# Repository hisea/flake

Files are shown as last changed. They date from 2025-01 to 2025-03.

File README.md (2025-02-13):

<div align="center">
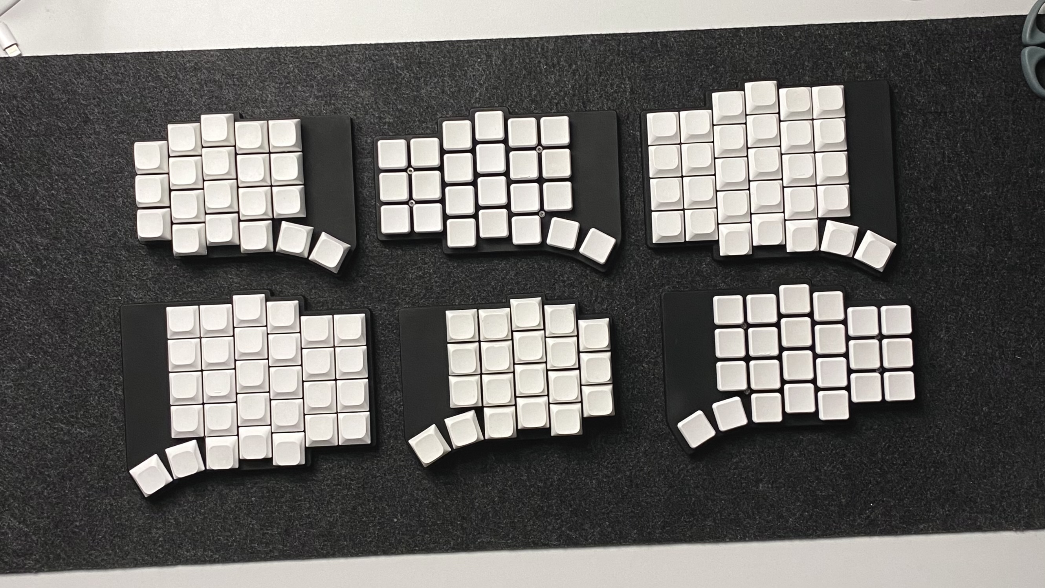
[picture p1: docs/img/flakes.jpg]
flake image
    
    <h3>Anywhy Flake</h3>
    <p><i>be productive, stay healthy and enjoy the process.</i></p>
</div>

# Why

By the 19th century, a need for a faster way of writing had emerged, which led to the invention of typewriters. Two centuries later, modern keyboards don't look much different from their predecessors, even though such design has been proven to be quite inefficient and often harmful.

Addressing these problems leads to huge benefits considering how often people use keyboards in the modern world.

# How

## Split

Regular keyboards are made in a single monolithic block, and the main problem is that such a form factor requires our forearms to meet in the center. To compensate for this, wrists are bent apart. This position creates an unnatural angle between the forearm and the wrist, which in the long term will likely lead to constant wrist pain.

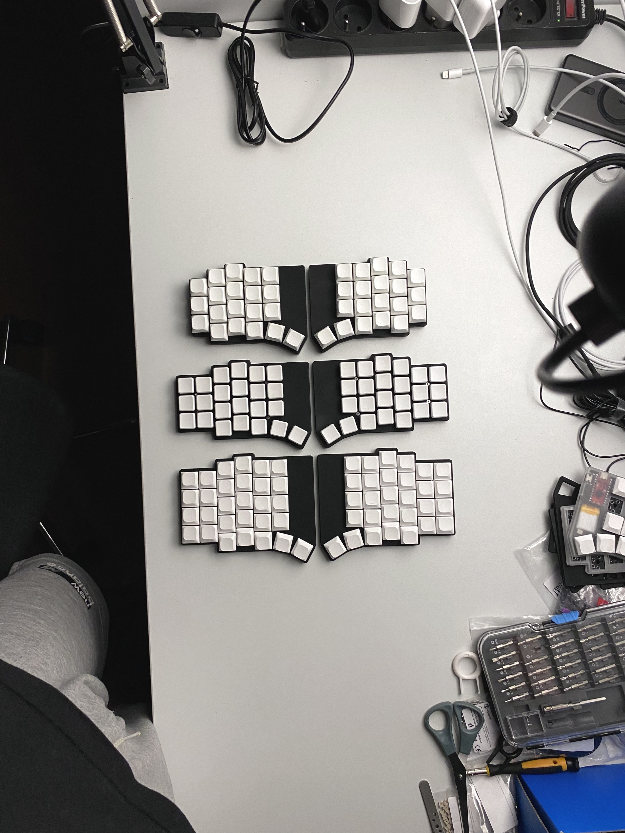
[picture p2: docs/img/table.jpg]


Each half of the split keyboard can be rotated and placed in any suitable way so everyone can adapt the setup to their personal preference, avoiding potential damage to the wrists. As a bonus, we get free space right between the halves which can be occupied by a trackpad, coffee, or even a cat =^..^=

## Stagger

If you take your hand and look at the fingers, you can notice that they are positioned horizontally. Now take a look at your keyboard - the keys are grouped in arrays that are shifted vertically, known as row-based stagger.

row-based stagger keyboard image

This well-known layout forces your fingers to move in a counterintuitive way. The solution to that problem is simple: we need to rearrange the keys in a more human-friendly way.

flake stagger image

As you can see, Flake has what's called a column-based stagger. Because of this, keys are located in the path of natural finger movement, which results in a much more pleasant typing experience and reduced fatigue.

## Key switches

There are a huge amount of various keyboard switches with different feel, size, sound, height and so on. Such variety is awesome, but the problem arrives when you have to chose one.

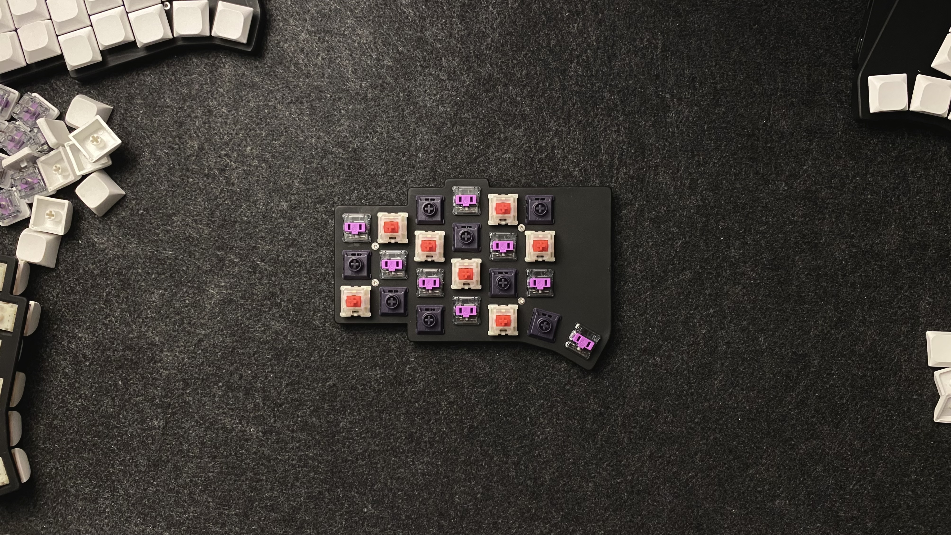
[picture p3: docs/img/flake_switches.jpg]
flake s image


To address this issue, Flake utilizes hot-swap sockets. There are two different sockets per key, allowing you to use any Cherry MX and low-profile Kailh Choc switches. This way, you can always experiment with the look and feel of the keyboard and change it according to your mood.

## Keys amount

There's a high chance that some might feel confused seeing such a small number of keys, considering user productivity is one of the priorities for Anywhy.

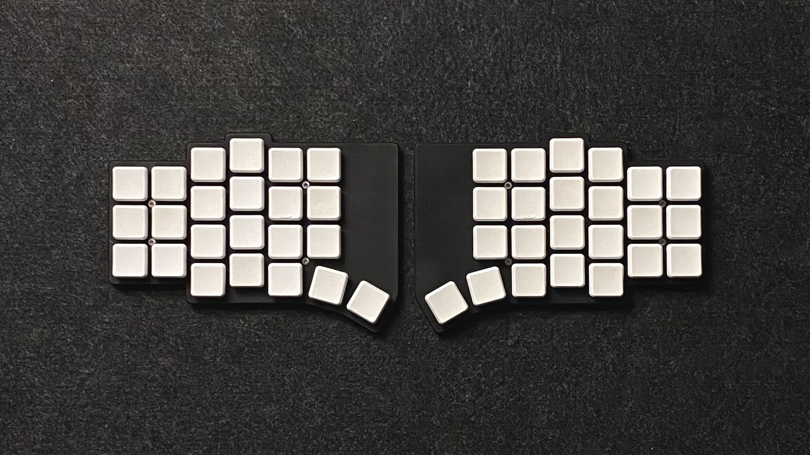
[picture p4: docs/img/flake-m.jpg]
flake s image


Indeed, Flake has fewer keys than most conventional keyboards, and that's not a compromise, but a feature. A large number of keys causes hands to move around to reach further-placed keys.

Having fewer keys doesn't mean less functionality. In fact, Flake is not only fully input-compatible with regular keyboards but also allows you to add more keys than most keyboards have. All thanks to [ZMK Firmware](https://zmk.dev) and its features such as [layers](https://zmk.dev/docs/keymaps#layers).

config showcase image

### Flake L

There's a Flake L with 58 keys for those who aren't ready to jump down the rabbit hole yet or just prefer more keys.

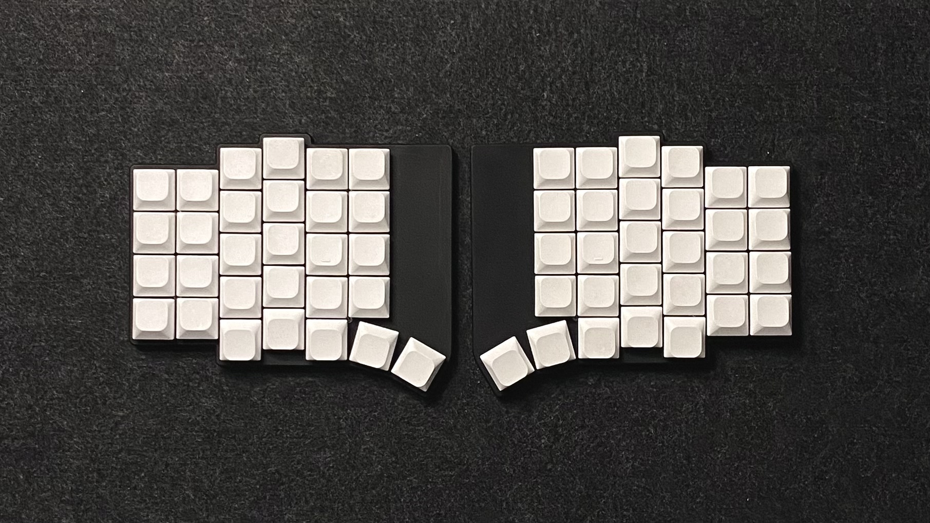
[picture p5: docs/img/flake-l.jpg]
flake l image


### Flake S

For people who strive for absolute comfort and compactness, there is also Flake S with 40 keys.

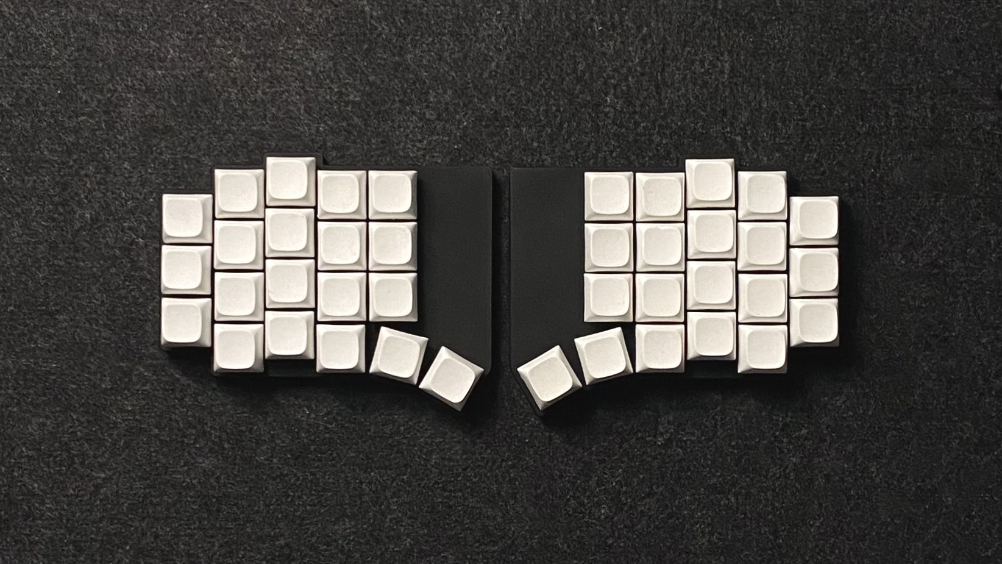
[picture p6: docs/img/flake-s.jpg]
flake s image


## Thickness

The keyboard has been designed to be as thin as possible while maintaining a sturdy construction.

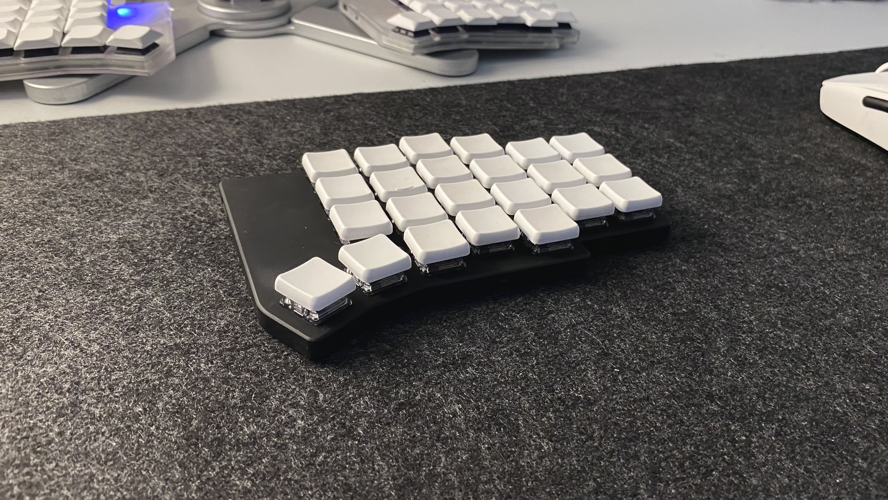
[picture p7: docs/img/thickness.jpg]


The keyboard body is only ~0.8 cm (without feet), which combined with the low-profile switches and caps, greatly enhances comfort.

# What

Flake supports both wired and wireless (Bluetooth) connection, which makes it perfect for both home usage with a PC or portable setup with a laptop, tablet, or even smartphone.

To achieve both types of connectivity, each half has two USB-C ports, one on the top and one on the inner side. The side port is used to connect the halves together, and then one of them (usually the left one) can be connected to any device using the top port, which is also used to charge the keyboard.

> Ports on the side are used only to communicate with each other, so they can't be used to charge the keyboard or to flash the new firmware

The keyboard allows for a maximum battery capacity of 200mah. On a single charge, the left half will last ~1 month and the right half will last over 4 months when used for 6 hours every day.

> The calculations are done with the nice!nano controller.

In order to use MX Switches, the special "plate" comes with the Flake which should be placed between the board and the switches.

# Build

If you want to build the keyboard yourself, check out [Guide](./docs/build_guide.md), which describes everything you need to build your own Flake. 

Also, make sure to check out the [Gallery ✨](./docs/gallery.md) with awesome Flake builds.

# Credits

Huge thanks to:

- [@foostan](https://github.com/foostan), the author of [Corne Keyboard](https://github.com/foostan/crkbd) which was my introduction to the world of ergonomic keyboards.
  
- [@pashutk](https://github.com/pashutk), the author of [Chocofi](https://github.com/pashutk/chocofi), an amazing tiny keyboard I've been using for a while.
  
- [@ebastler](https://github.com/ebastler/) for his amazing [marbastlib](https://github.com/ebastler/marbastlib) which is being used as the basis for footprint switches

- [@josefadamcik](https://github.com/josefadamcik), the author of [Sofle](https://github.com/josefadamcik/SofleKeyboard) which gave huge inspiration for the Flake's key layout.
  
- [@petejohanson](https://github.com/petejohanson) for creating [ZMK Firmware](https://github.com/zmkfirmware/zmk) and all the [contributors](https://github.com/zmkfirmware/zmk/graphs/contributors) that make it better each day.

- Everyone working on [KiCad](https://gitlab.com/kicad/code/kicad) and [FreeCAD](https://github.com/FreeCAD/FreeCAD), for creating such powerful open source tools

- People from the [ZMK discord server](https://zmk.dev/community/discord/invite) for being so kind while helping me learn how to design PCB and how to debug and solve various problems.

- Finally, thank you to everyone who explores unpopular technologies, digs into niche topics, and makes amazing things possible.

## Stars

Your stars give motivation to keep improving the project :)

Star History Chart (https://star-history.com/#anywhy-io/flake&Date)

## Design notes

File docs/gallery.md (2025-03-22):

# Anywhy Flake Gallery

Welcome to the gallery, here you will find amazing Flake builds made by people. This page will be constantly expanding, so if you have a build you want to share, feel free to contact me and I'll add it here.

## by [@peppapighs](https://www.reddit.com/r/ErgoMechKeyboards/comments/1jbw0kt/my_custom_flake/)

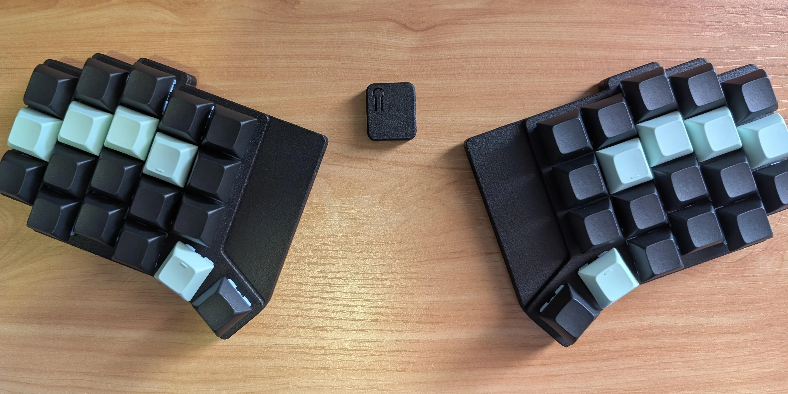
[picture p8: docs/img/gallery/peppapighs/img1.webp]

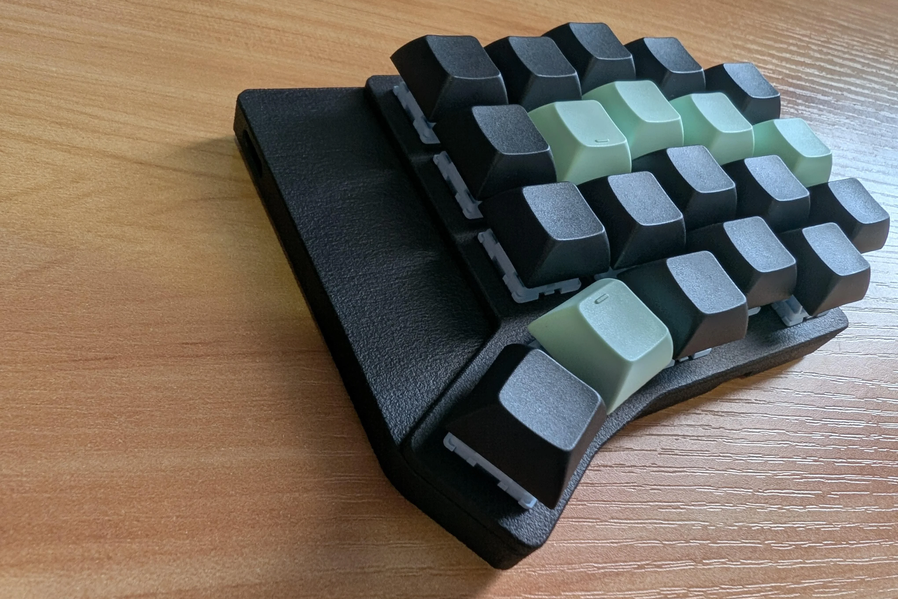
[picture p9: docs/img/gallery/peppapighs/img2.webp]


Flake S with modified PCB adding through-holes for MCU mounting

## by [@caiodelgado](https://www.reddit.com/r/ErgoMechKeyboards/comments/1iz07kw/anywhy_flake_choc_v1_robinsunset_tenting/)

Flake with Choc v1 Robin switches, 3d-printed keycaps and tenting legs

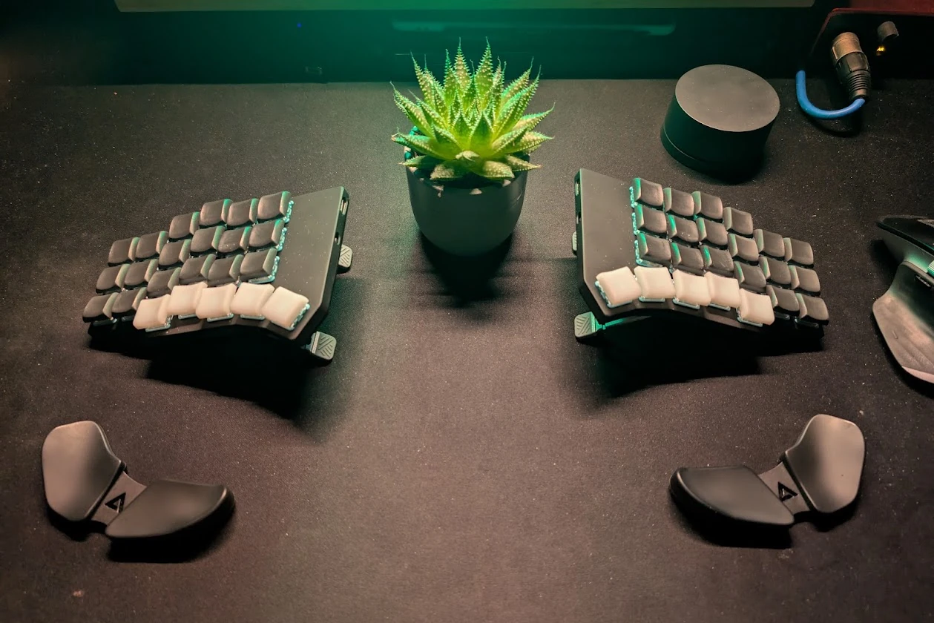
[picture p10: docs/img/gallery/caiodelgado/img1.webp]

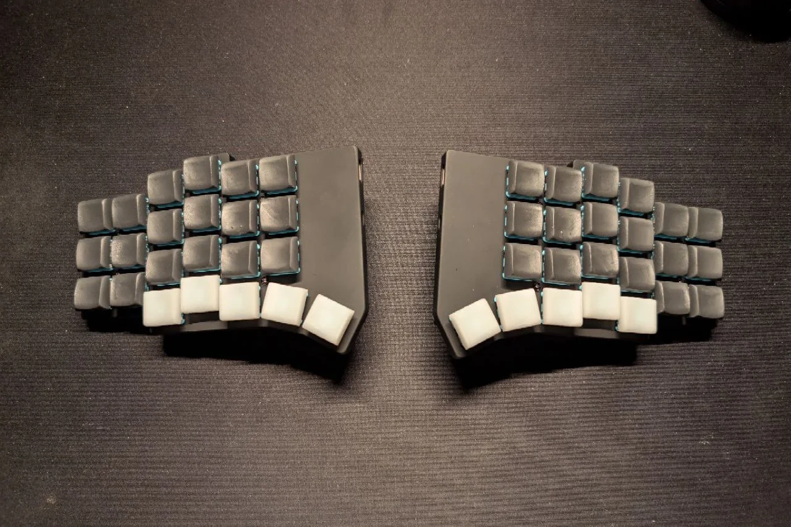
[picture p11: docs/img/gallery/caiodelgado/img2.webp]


## by [@kurisutofujp](https://www.reddit.com/r/ErgoMechKeyboards/comments/1iirgyt/comment/mb9034h/)

Snow-white Flake L with MX switches

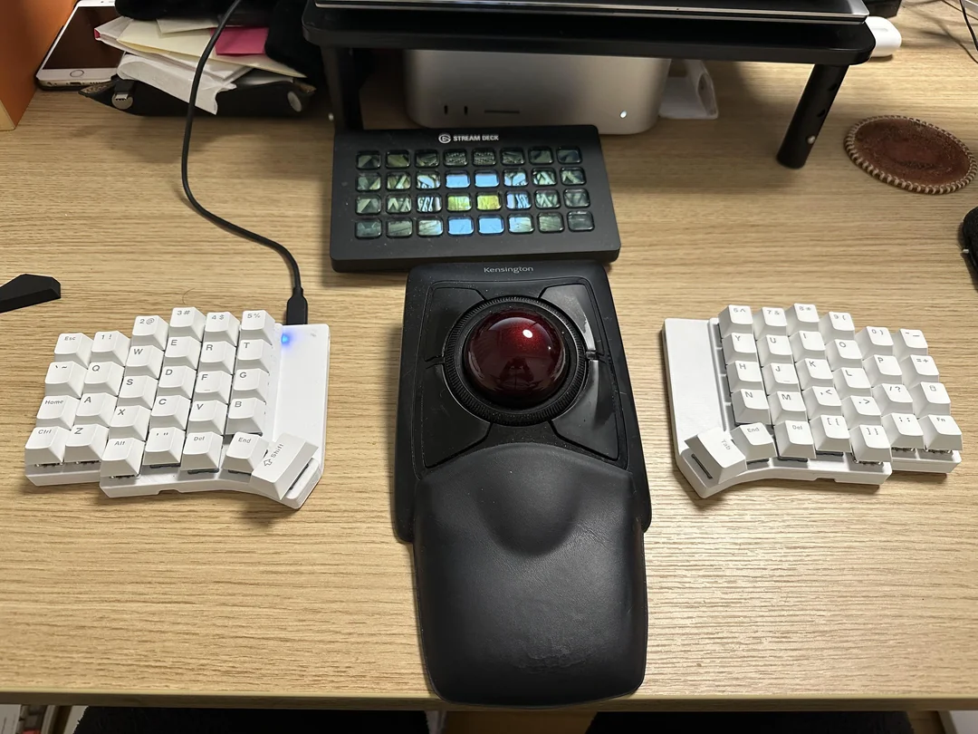
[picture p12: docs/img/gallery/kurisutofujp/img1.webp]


## by [@devpew](https://www.reddit.com/r/ErgoMechKeyboards/comments/1ieevvh/flake/)

Clean white Flake M with black keyscaps

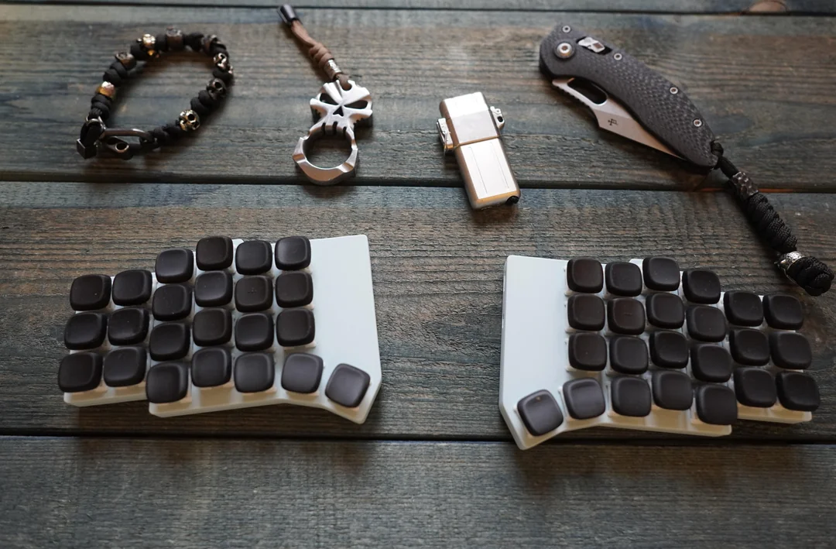
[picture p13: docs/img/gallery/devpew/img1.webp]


## by [@CaptLynx](https://www.reddit.com/r/ErgoMechKeyboards/comments/1ic3nkc/caitlynarcane_themed_anywhy_flake/)

The design is inspired by Caitlin, a character from the Arcane series.

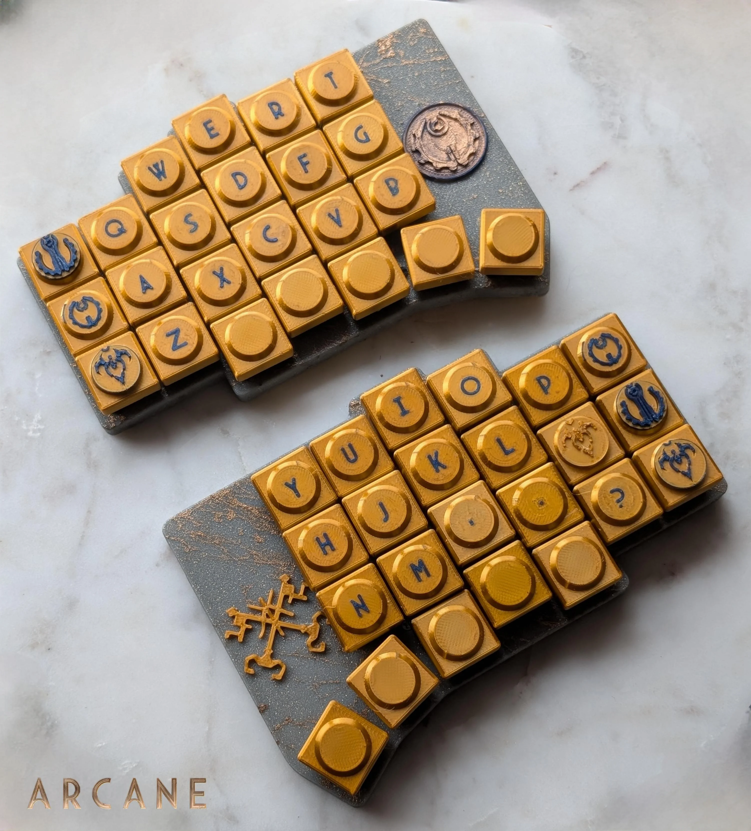
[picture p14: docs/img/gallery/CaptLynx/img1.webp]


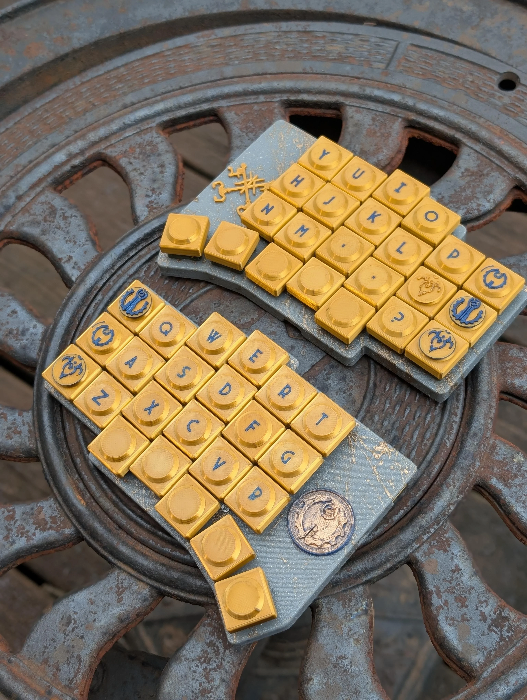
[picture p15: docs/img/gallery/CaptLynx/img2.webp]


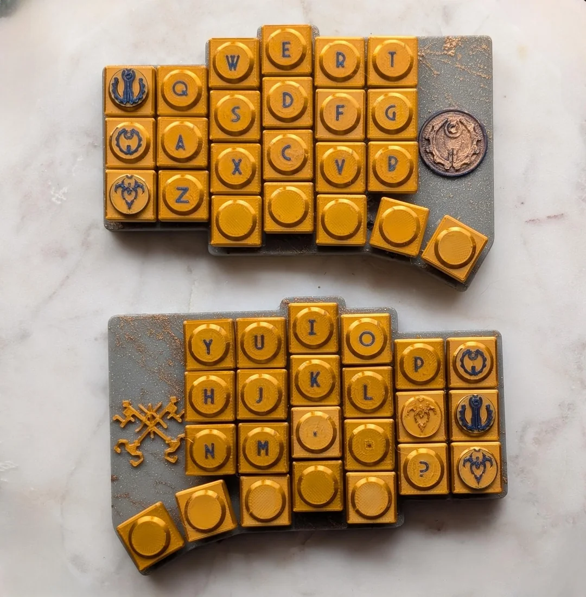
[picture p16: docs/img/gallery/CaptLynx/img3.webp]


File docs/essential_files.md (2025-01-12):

# Where is the PCB Gerber file?

You can find these files in their respective directories based on keyboard size:

```
pcb/<keyboard-size>/production/
```

Download the appropriate Gerber files for your keyboard version:

- [Flake S/M](https://github.com/anywhy-io/flake/blob/main/pcb/M%2CS/production/Flake.zip)
- [Flake L](https://github.com/anywhy-io/flake/blob/main/pcb/L/production/Flake-L.zip)
  
# Where are the Enclosure files?

Enclosure files are organized by keyboard size in the following directory structure:

```
enclosure/<keyboard-size>/
```

Select the enclosure files matching your keyboard version:

- [Flake S](https://github.com/anywhy-io/flake/tree/main/enclosure/S)
- [Flake M](https://github.com/anywhy-io/flake/tree/main/enclosure/M)
- [Flake L](https://github.com/anywhy-io/flake/tree/main/enclosure/L)

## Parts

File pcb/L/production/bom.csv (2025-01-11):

Designator | Footprint | Quantity | Value | LCSC Part #
BT1, BT2 | JST_1.25mm_mid-mount | 2 | Battery
D1, D10, D11, D12, D13, D14, D15, D16, D17, D18, D19, D2, D20, D21, D22, D23, D24, D25, D26, D27, D28, D29, D3, D30, D31, D32, D33, D34, D35, D36, D37, D38, D39, D4, D40, D41, D42, D43, D44, D45, D46, D47, D48, D49, D5, D50, D51, D52, D53, D54, D55, D56, D57, D58, D6, D7, D8, D9 | D_SOD-323_HandSoldering | 58 | D
J1, J2 | USB-C_6Pin_Mid-mount | 2 | USB_C_Receptacle_PowerOnly_6P
RSW1, RSW2 | TS-1289VE-4 | 2 | Reset_SW
SW1, SW10, SW11, SW12, SW13, SW14, SW15, SW16, SW17, SW18, SW19, SW2, SW20, SW21, SW22, SW23, SW24, SW25, SW26, SW27, SW28, SW29, SW3, SW30, SW31, SW32, SW33, SW34, SW35, SW36, SW37, SW38, SW39, SW4, SW40, SW41, SW42, SW43, SW44, SW45, SW46, SW47, SW48, SW49, SW5, SW50, SW51, SW52, SW53, SW54, SW55, SW56, SW57, SW58, SW6, SW7, SW8, SW9 | SW_MX_Choc-v1v2_Hotswap | 58 | SW_Push
U1, U2 | ProMicro_SMD | 2 | ProMicro

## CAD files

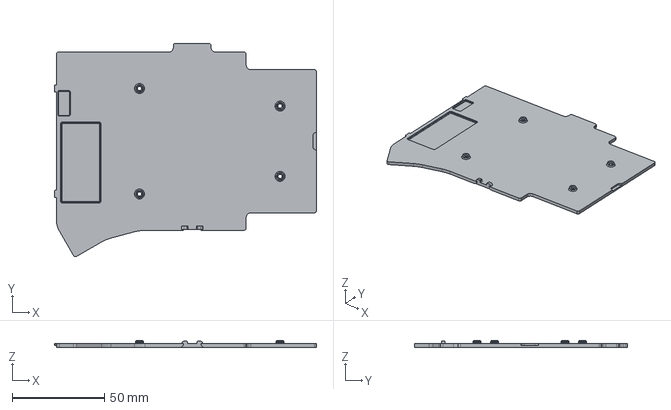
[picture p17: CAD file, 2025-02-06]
enclosure/L/Enclosure-L-Bottom-Right.step
141.6 x 115.4 x 3.70 mm

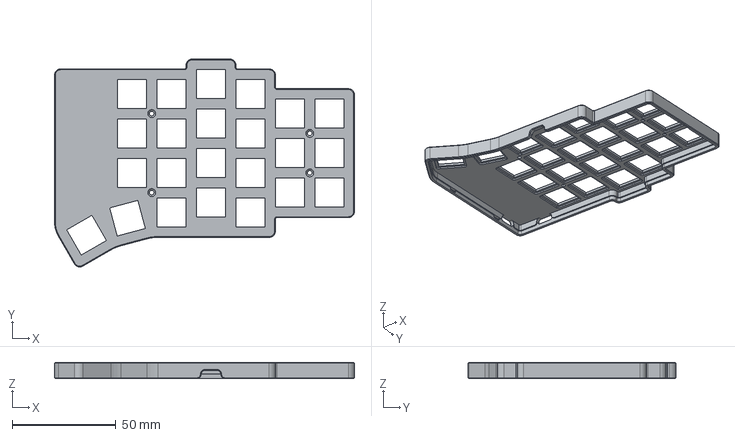
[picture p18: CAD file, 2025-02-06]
enclosure/M/Enclosure-M-Top-Right.step
144.2 x 100.0 x 7.80 mm

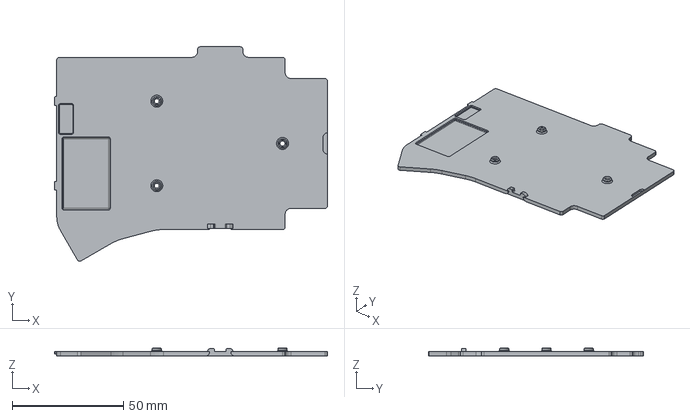
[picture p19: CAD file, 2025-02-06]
enclosure/S/Enclosure-S-Bottom-Right.step
122.6 x 96.4 x 3.70 mm

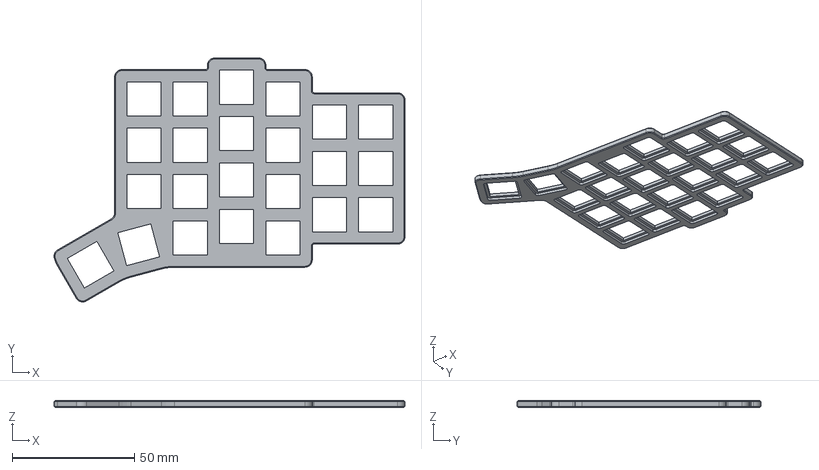
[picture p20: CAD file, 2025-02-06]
enclosure/M/Enclosure-M-Plate-Right.step
143.8 x 100.0 x 2.80 mm

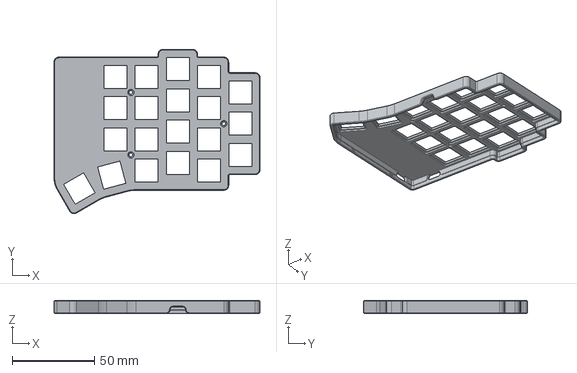
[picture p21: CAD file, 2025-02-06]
enclosure/S/Enclosure-S-Top-Right.step
125.2 x 100.0 x 7.80 mm

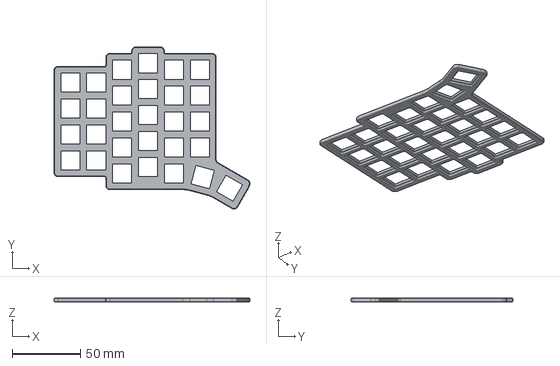
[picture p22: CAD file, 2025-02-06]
enclosure/L/Enclosure-L-Plate-Left.step
143.8 x 119.0 x 2.80 mm

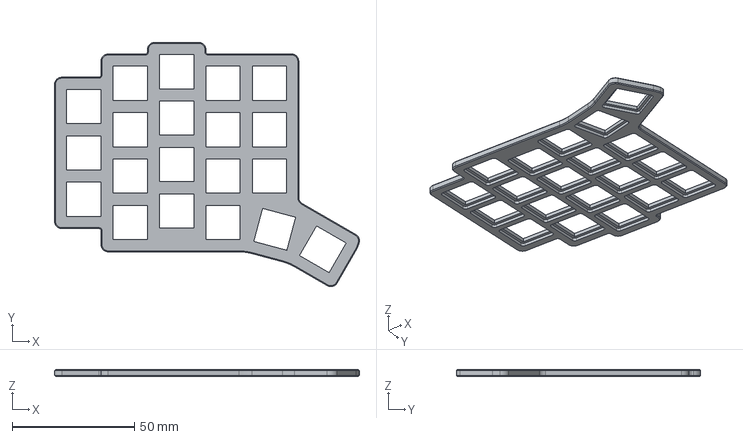
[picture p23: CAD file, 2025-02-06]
enclosure/S/Enclosure-S-Plate-Left.step
124.8 x 100.0 x 2.80 mm

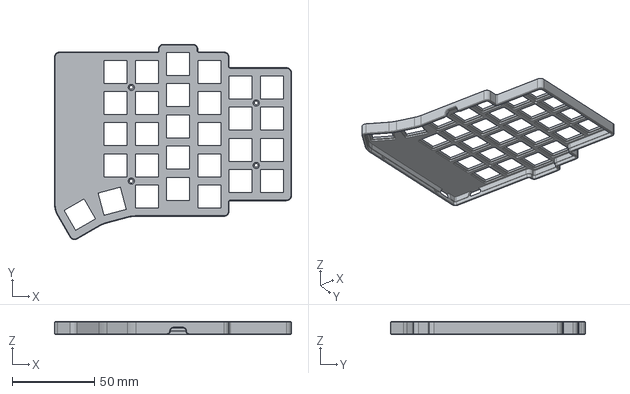
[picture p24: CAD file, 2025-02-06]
enclosure/L/Enclosure-L-Top-Right.step
144.2 x 119.0 x 7.80 mm

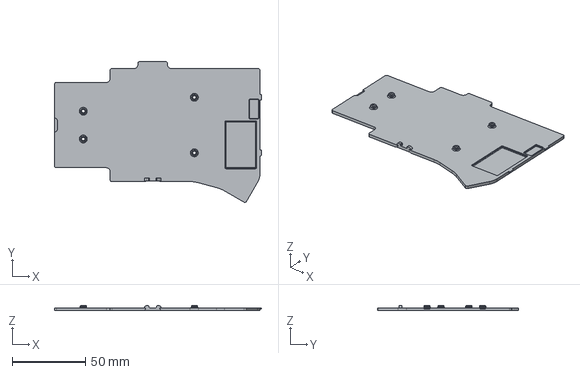
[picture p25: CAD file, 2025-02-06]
enclosure/M/Enclosure-M-Bottom-Left.step
141.7 x 96.4 x 3.70 mm

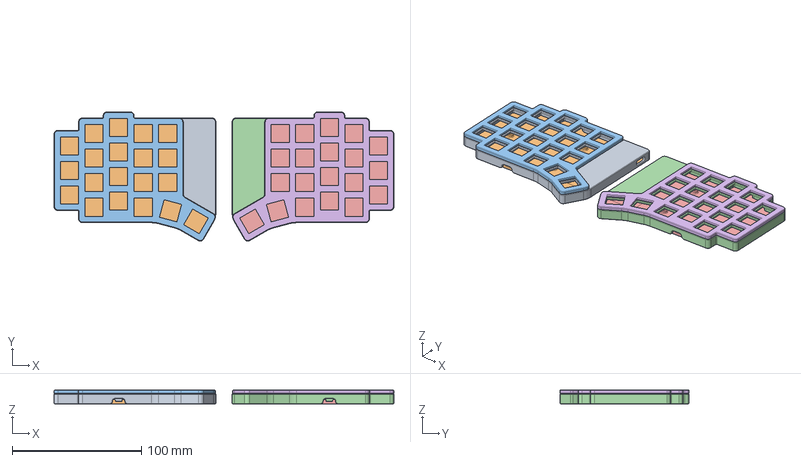
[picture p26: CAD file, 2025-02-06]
enclosure/S/Enclosure-S.FCStd
263.0 x 100.0 x 10.8 mm
Top-Left
Bottom-Left
Plate-Left
Top-RIght
Bottom-Right
Plate-Right

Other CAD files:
enclosure/L/Enclosure-L-Bottom-Left.step
enclosure/M/Enclosure-M-Top-Left.step
enclosure/S/Enclosure-S-Bottom-Left.step
enclosure/L/Enclosure-L-Plate-Right.step
enclosure/M/Enclosure-M-Bottom-Right.step
enclosure/L/Enclosure-L-Top-Left.step
enclosure/M/Enclosure-M-Plate-Left.step
enclosure/S/Enclosure-S-Plate-Right.step
enclosure/L/Enclosure-L.FCStd
enclosure/M/Enclosure-M.FCStd
enclosure/S/Enclosure-S-Top-Left.step

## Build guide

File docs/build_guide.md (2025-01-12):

# How to Build the Flake?

## Components

To build the Flake, you'll need the following materials:

| Name | Count | Remarks |
|:---|:---|:---|
| PCB | 1 set | |
| MX hot-swap sockets | 40/46/58  | |
| Choc hot-swap sockets | 40/46/58  | |
| Diodes | 40/46/58  | 1N4148 SOD-323 |
| Switches | 40/46/58  | Choc V1/V2 or MX switches |
| Keycaps | 40/46/58  | Compatible with your switches |
| Controllers | 2 | Any ProMicro-compatible controller |
| USB-C ports | 2 | 6 pins, mid-mount 1.6mm ([example](https://www.lcsc.com/product-detail/USB-Connectors_BXCONN-UC19-0B06F65011_C36936556.html))|
| Reset buttons | 2 | TS-1289VE-4 |
| Enclosure | 1 set | |
| Plates | 1 set | Required for MX switches |
| M2 Screws | 8 | Flat countersunk 8mm (e.g., DIN965)  |
| M2 Hex nuts | 8 | DIN439 (thinner than regular) |
| Rubber feet | 8 | 6x2mm |
| Battery sockets | 2 | JST 1.25 with straight pins |
| Batteries | 2 | 402030 (or smaller) with JST 1.25 |

[Here](essential_files.md) you can read where to find all the files you need for the PCBs and enclosures manufacture.

> **Note**: MX switch plates and batteries are optional depending on your build:
> - Skip the plates if are going to use only Choc switches
> - Omit batteries if plan to use Flake only by wire

# Assembly

> ⚠️ **Important**: The soldering process can be challenging, especially for beginners. This guide is structured to tackle the most difficult parts first to minimize component waste if something goes wrong. I recommend reading the guide completely before starting assembly. For first-time builders, having spare PCBs and parts is advised.

## Preparing the PCB

The PCB consists of two halves connected by breakaway tabs.

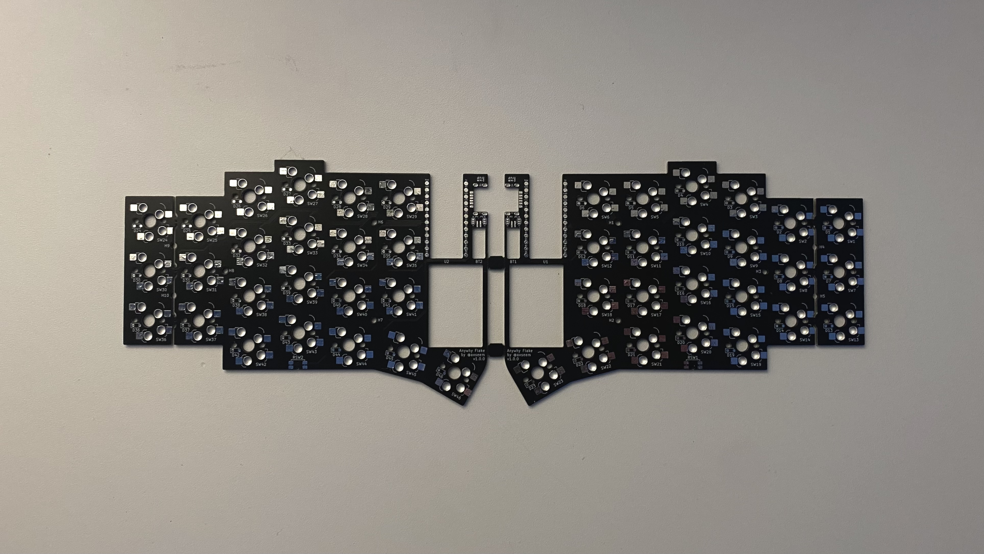
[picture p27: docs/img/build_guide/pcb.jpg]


Carefully separate the halves using pliers. Handle the top section with extra care - it remains fragile until the controller is installed.

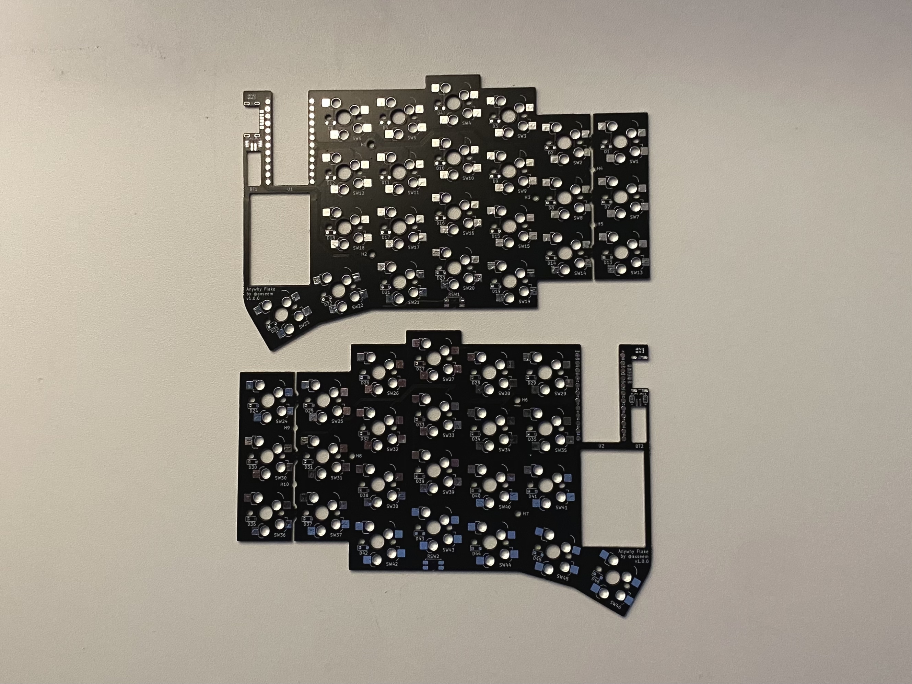
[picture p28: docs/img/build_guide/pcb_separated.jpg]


Since the assembly process is identical for both halves, this guide will focus on building one half. Simply repeat these steps for the second half.

Select the PCB half you'll assemble first.

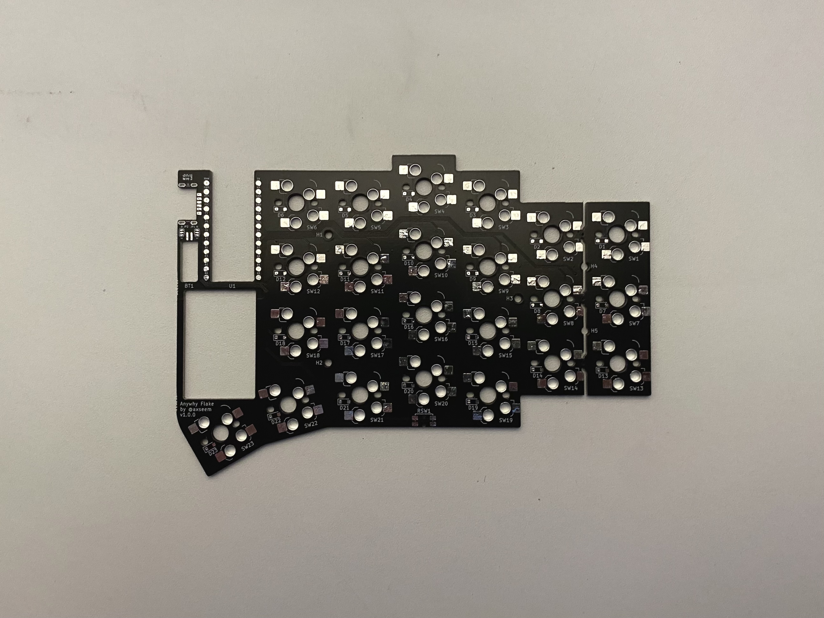
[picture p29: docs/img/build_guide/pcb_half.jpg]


If you're building the S version with 40 keys, now is the time to remove the outer column. To do this, hold the PCB with the bottom side facing you (as shown in the previous image) and gently fold it toward you until it breaks.

For M or L versions, keep the PCB as is.

## USB Port

> **Note**: The outer pins and legs are connected to the GND (Ground) net, which contains substantial copper and requires more heat to solder properly. To ensure good connection, use additional flux and slightly increase the iron temperature, but avoid keeping the iron on the pad for too long.

Place the USB-C port in the appropriate cutout marked as J1 or J2, depending on which half you're working on. Ensure the port's back sits flush against the PCB.

Apply a small amount of flux over the pins. Touch each of the six pads briefly with your soldering iron tip and solder wick. Use just enough solder to secure the port without creating bridges between pins.

If bridges occur, apply flux and remove excess solder with your iron.

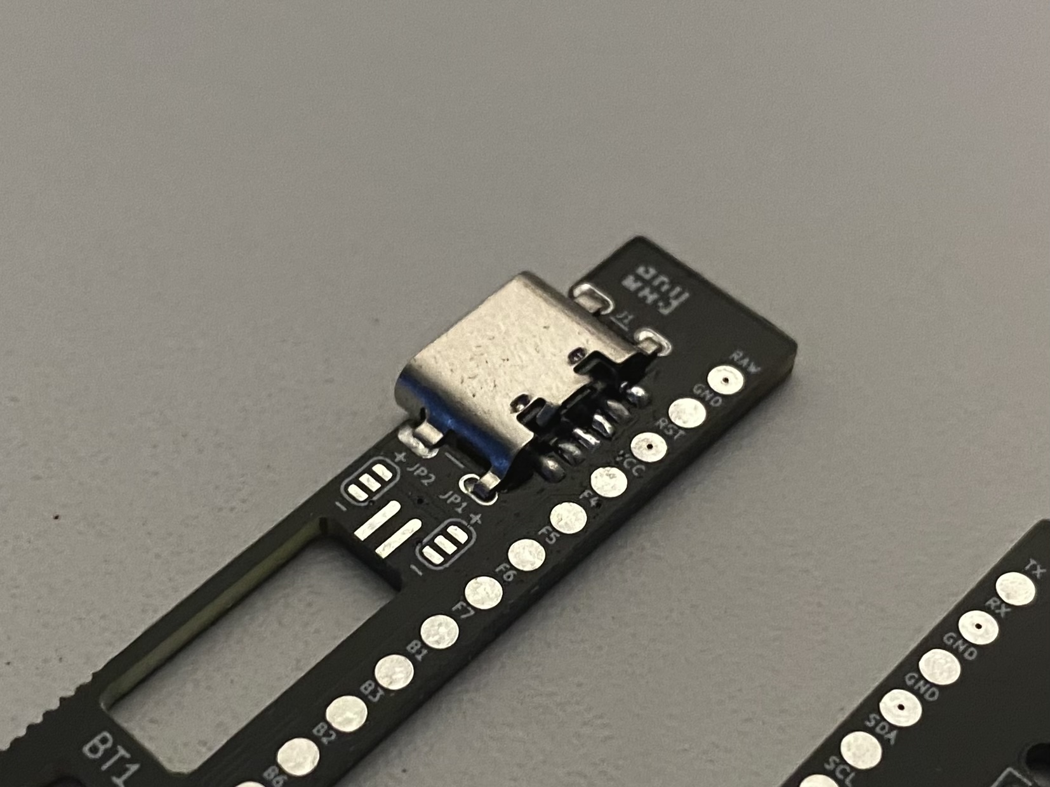
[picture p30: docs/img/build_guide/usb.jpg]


After soldering the pins, flip the PCB and solder the legs. Hold the iron over each hole for a few seconds to allow the solder to flow into it. Use a moderate amount of solder so it will not stick out of the PCB surface.

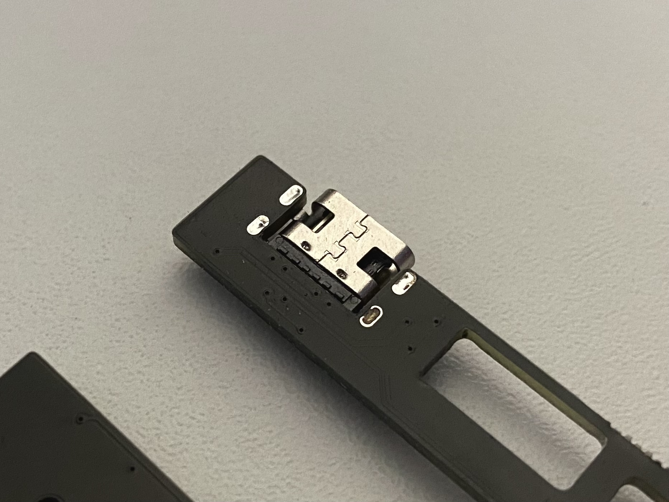
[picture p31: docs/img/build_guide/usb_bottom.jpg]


> **Tip**: A good practice is to test the connections with a multimeter after soldering. The pins are symmetrically connected to the nets:
>
> | Pins | Net | Description |
> |------|-----|-------------|
> | 1, 6 | GND | Ground      |
> | 2, 5 | VCC | Power       |
> | 3, 4 | RX  | Data        |
>
> Locate these network names on the controller pads and verify proper connections.

## Battery Connector

Add solder to one of the long connector pads and apply flux. Insert the JST 1.25 socket into the BT1 hole (or BT2 for the other half) with the cutout facing downward. Hold the connector with tweezers, ensuring the legs lay flat on the pads. Apply soldered iron tip to the leg above the pre-soldered pad. Once one leg is secured, solder the second leg.

Verify the connector sits parallel to the PCB. If needed, reheat the legs to adjust position. Check for any bridges between legs.

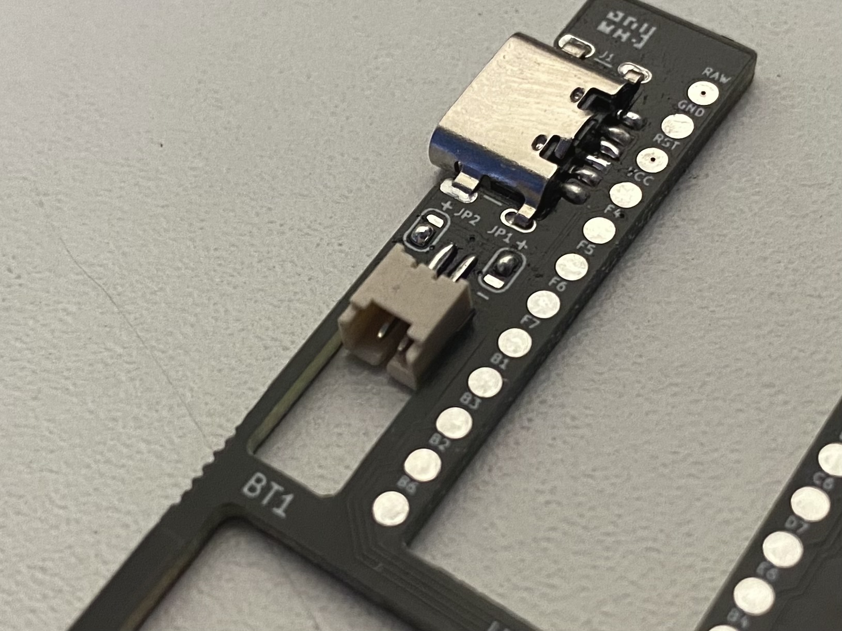
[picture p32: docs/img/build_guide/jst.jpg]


Next, solder jumpers JP1 and JP2 (or JP3 and JP4, depending on the half). First, insert the battery into the socket and note the wire polarity from left to right. Remove the battery and solder the jumpers accordingly. For example, if you noted black (negative) then red (positive), solder the center and bottom pad on the left jumper and the center and top pad on the right jumper.

> ⚠️ **Warning**: Incorrect polarity can damage both controller and battery. Double-check all connections before proceeding.

PCB image

## Reset Switch

Position the reset switch at the bottom of the PCB in the RSW1 (or RSW2) location. Apply flux to the pins and carefully solder them using solder wire. Remove the excessive solder.

> **Note**: Two of the four pins connect to GND, so don't hesitate to use plenty of flux.

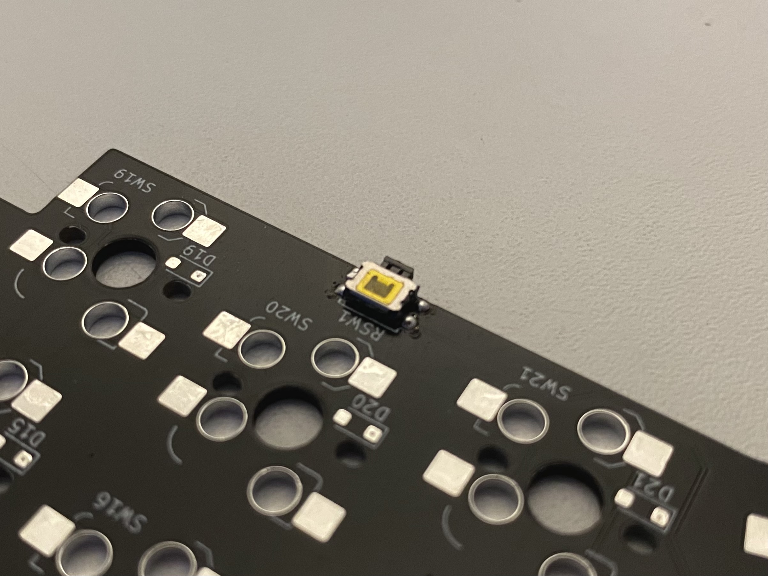
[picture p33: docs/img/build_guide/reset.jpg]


## Initial Sockets

Before mounting the controller, solder the sockets adjacent to it. These become difficult to access once the controller is in place.

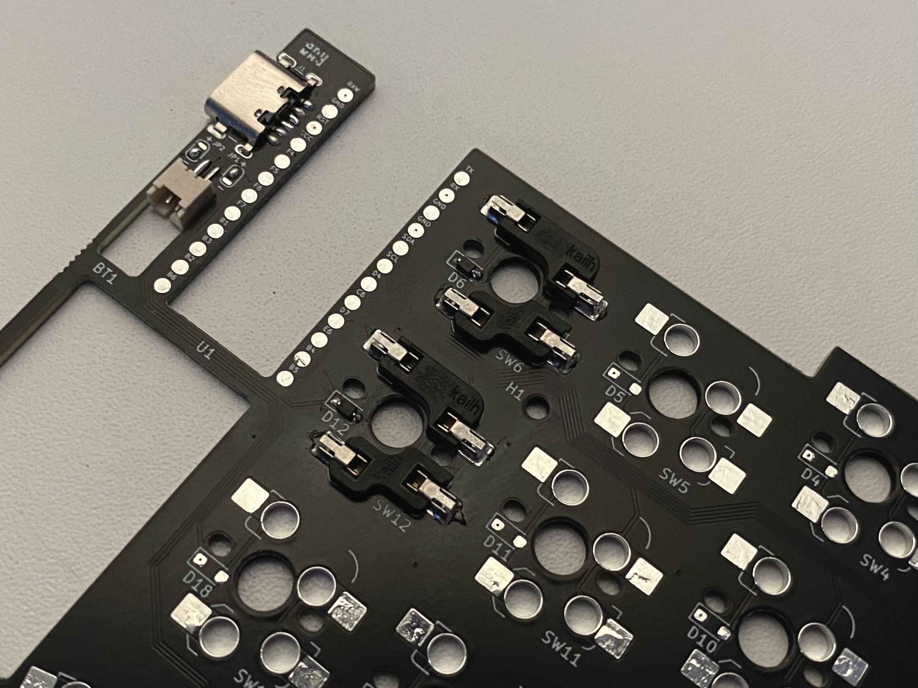
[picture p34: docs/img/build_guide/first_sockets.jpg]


## Per Key Components

Each key requires one diode and two sockets. Begin with the diode installation:

1. Apply solder to one pad
2. Using tweezers, hold the diode while heating the solder
3. Place the diode ensuring correct polarity
4. Once secured, solder the remaining leg

PCB image

After the diode is installed, mount the sockets (MX on top, Choc on bottom). Hold the soldering iron at approximately 45° to the table and insert it into the socket's side leg. Feed solder just below the tip to ensure even distribution. Repeat for the other leg and second socket.

## Controller Installation

Position the controller in the cutout labeled U1 (or U2). Use the silkscreen and top holes for proper alignment.

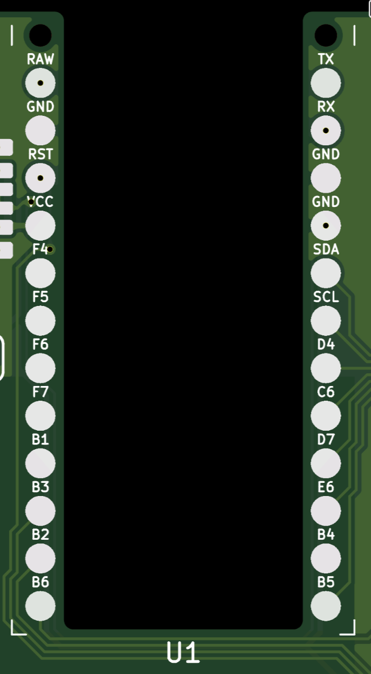
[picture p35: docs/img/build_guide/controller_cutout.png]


For optimal results, temporarily insert pins in the top two holes without soldering them. This helps maintain position during soldering.

Begin by soldering opposite corners, preferably choosing pads with minimal copper (aka not GND or RAW). I prefer B6 followed by TX pad.

Apply flux generously to the chosen hole. Insert solder wire and touch both the hole ring and solder with the iron tip. Push the wire in until all the solder is absorbed. Melt the joint and press down on the controller with the tweezers. Repeat for the opposite hole. When done correctly, the controller should sit flush against the PCB.

> Tip: Since direct pad contact is difficult, consider using a hot plate during soldering. Alternative heating methods (like a regular fan) can help. When filling holes, keep the iron in place for several seconds to distribute heat evenly. To avoid controller damage, touch only the solder bubble, not the hole ring.

After securing the controller, remove the temporary legs and solder all remaining holes. Use plenty of flux. After soldering all connections, apply flux and remove any excess solder with the iron.

The controller should sit flat with no protruding solder.

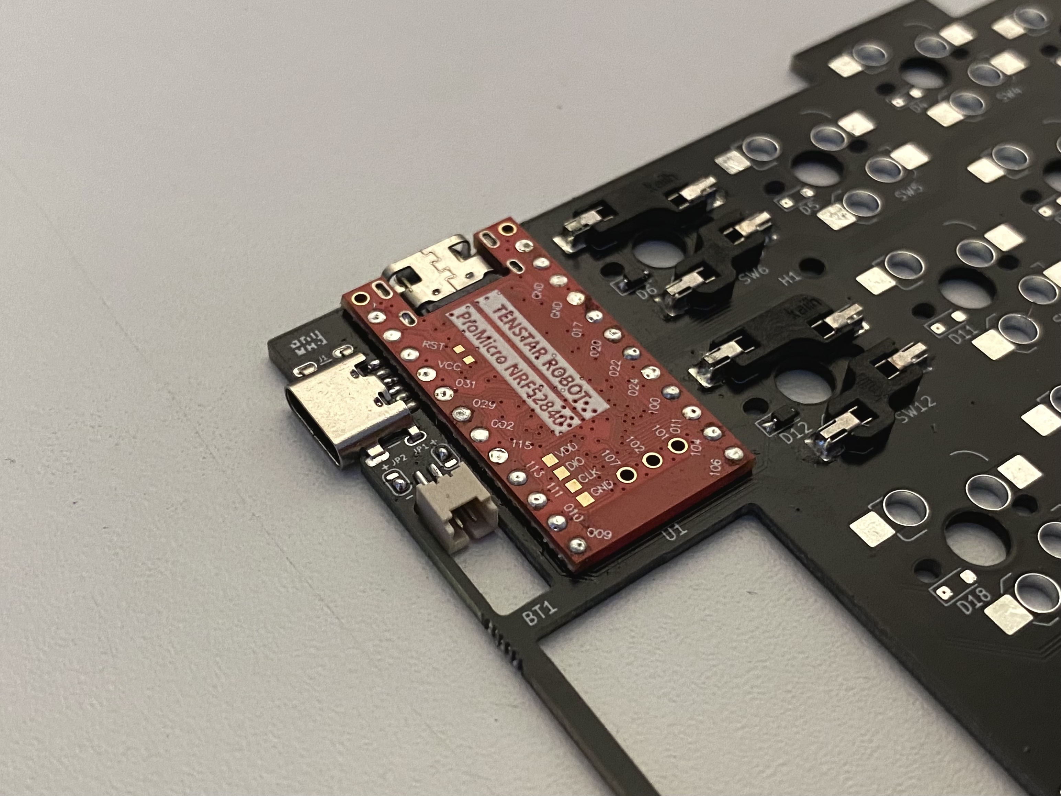
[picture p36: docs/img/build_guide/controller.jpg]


## Remaining Diodes and Sockets

Complete the installation of remaining diodes and sockets following [the same process as before](#per-key-components). It's recommended to install all diodes first, then proceed with socket installation.

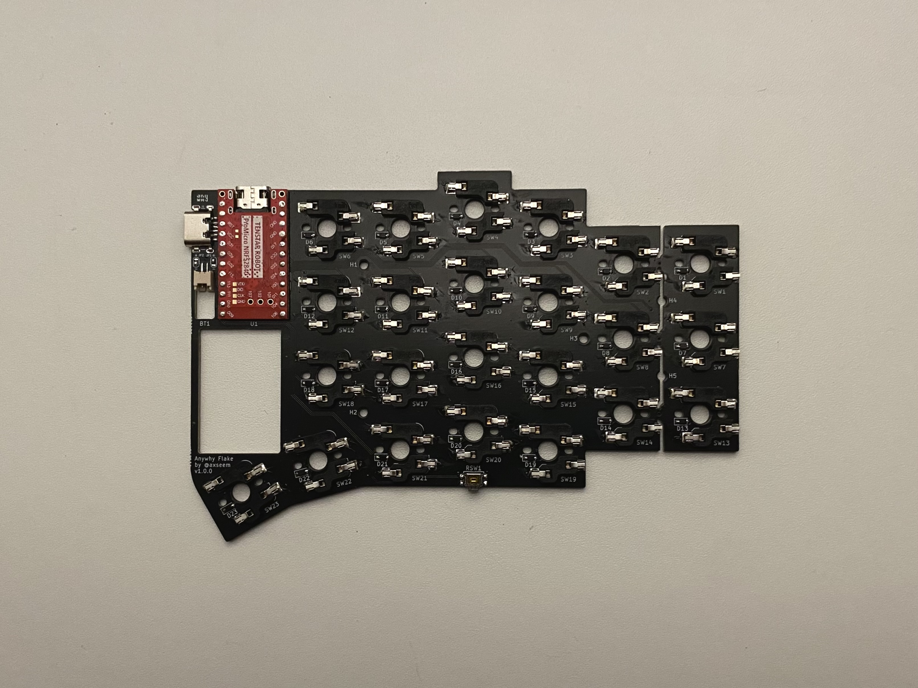
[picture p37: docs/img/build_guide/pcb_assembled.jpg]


## Enclosure Assembly

Place the PCB in the enclosure as shown. Carefully connect the battery, avoiding vertical force on the JST connector to prevent damage. Position the battery in its designated cutout and route wires to avoid interference with the lid.

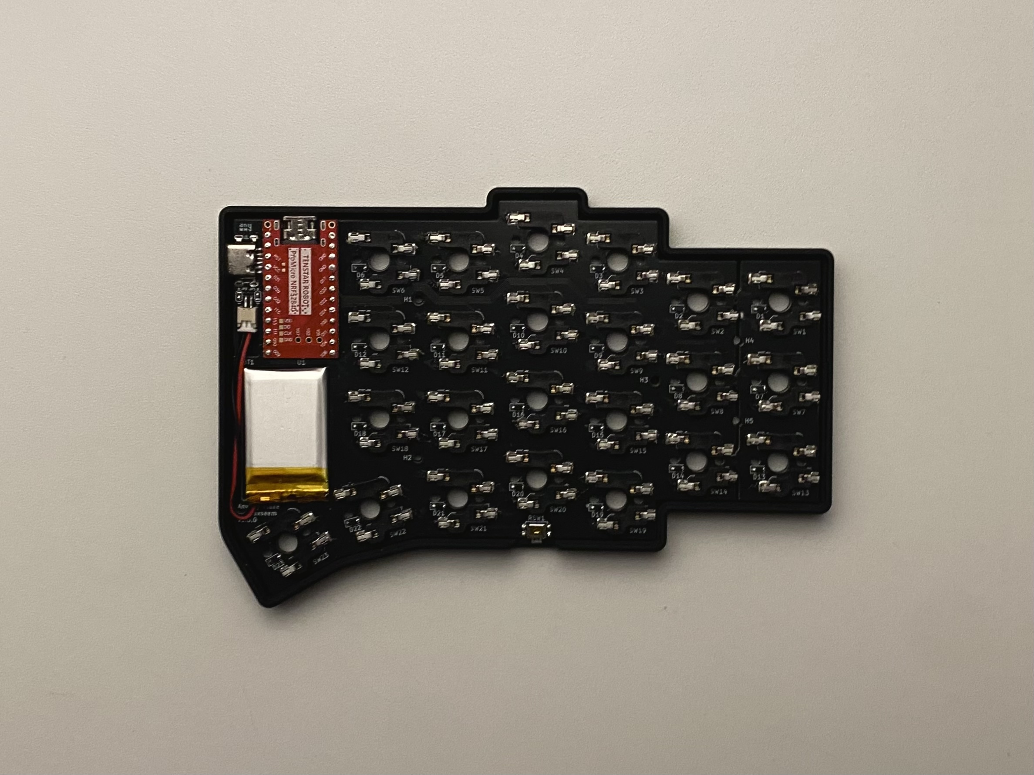
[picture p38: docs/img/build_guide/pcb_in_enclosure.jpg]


Place the lid and ensure it sits evenly. Insert hex nuts into the holes, compress the enclosure, and insert screws from the bottom. Add rubber feet, positioning them oppositely on the second half to eliminate gaps when halves are placed back-to-back.

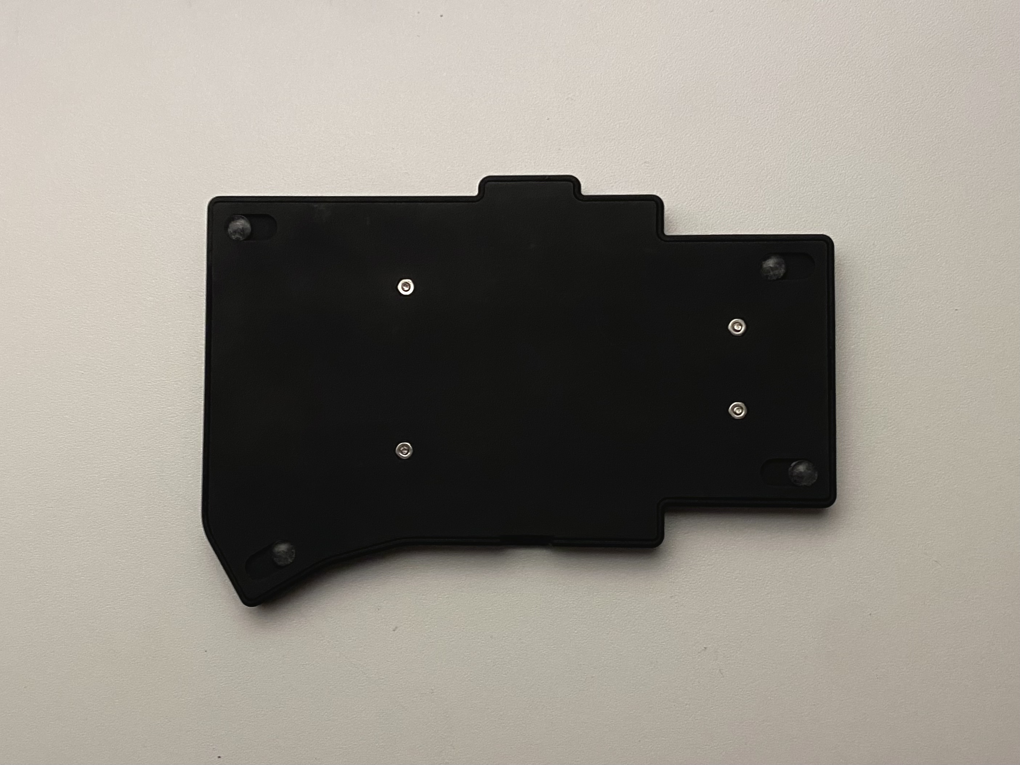
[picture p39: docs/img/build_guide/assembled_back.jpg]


Repeat the entire process for the second half.

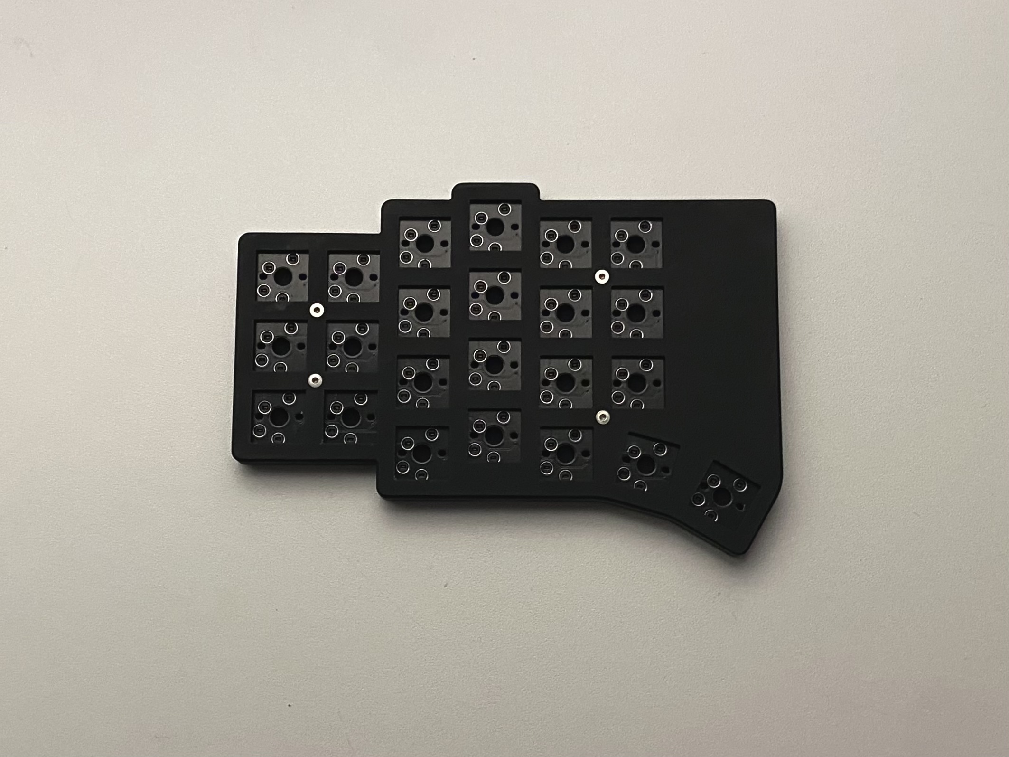
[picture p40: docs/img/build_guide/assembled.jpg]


## Final Assembly

Insert your chosen switches into the appropriate sockets (MX in top socket; Choc in bottom socket). Attach keycaps to complete the physical assembly. To make your Flake fully functional, you'll need to flash the firmware - refer to the [flashing guide](flashing_guide.md) for instructions.

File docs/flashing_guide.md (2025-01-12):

# How to Flash the Flake?

## Getting the Firmware

Before your keyboard can function, you'll need to flash it with the appropriate firmware. The firmware is available in the [GitHub repository](https://github.com/anywhy-io/flake-zmk-module).

To download the firmware:
1. Visit the repository's [Actions page](https://github.com/anywhy-io/flake-zmk-module/actions)
2. Select the most recent successful build (indicated by a green checkmark)
3. Download the firmware package

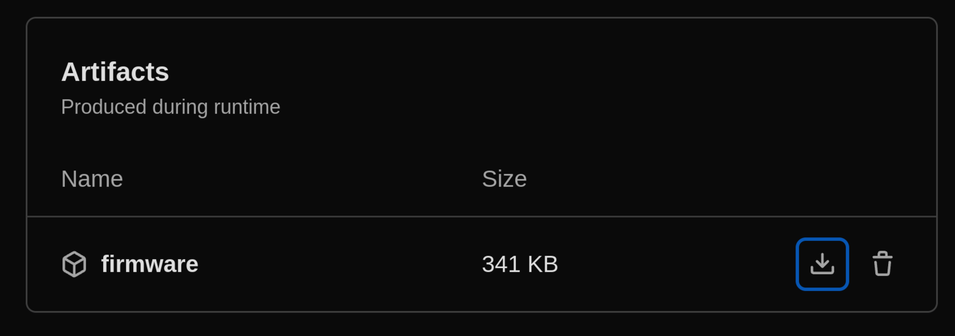
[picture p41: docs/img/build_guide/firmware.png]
Firmware download page


## Flashing Process

### Left Half
1. Connect the left half of your keyboard to your computer via USB
2. Press the reset button twice quickly to enter bootloader mode
   - The keyboard will appear as a storage device in your file manager
3. Locate the firmware file beginning with "anywhy_flake_left..." (with `.uf2` extension)
4. Copy this file to the keyboard's storage device
   - The device will automatically disconnect once flashing is complete

### Right Half
1. Disconnect the left half and connect the right half
2. Repeat the same process using the file beginning with "anywhy_flake_right..."

## Configuring with ZMK Studio

### Initial Connection
1. Reconnect the left half of the keyboard
2. Navigate to [ZMK Studio](https://zmk.studio) website

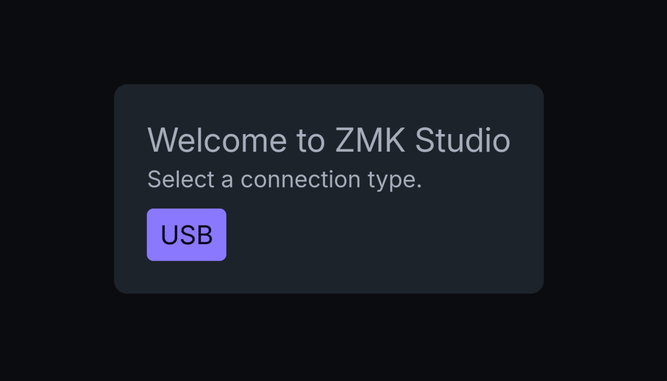
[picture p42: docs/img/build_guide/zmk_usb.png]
ZMK Studio USB connection


3. Click the USB button and select "Anywhy Flake" from the device list

### Unlocking the Keyboard

To unlock the keyboard's configuration:

1. Access the second layer by holding down the leftmost thumb key on the right half
2. Press the lowest key in the extra index finger column on the left half

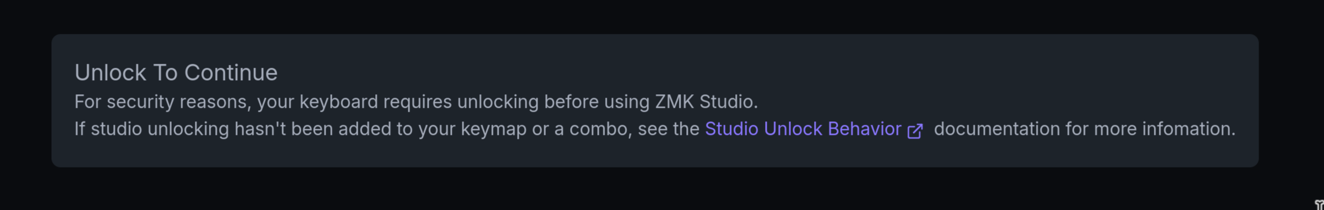
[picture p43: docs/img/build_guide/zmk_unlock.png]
ZMK Studio unlock process


This will give you access to the ZMK Studio interface where you can customize your keyboard's settings.

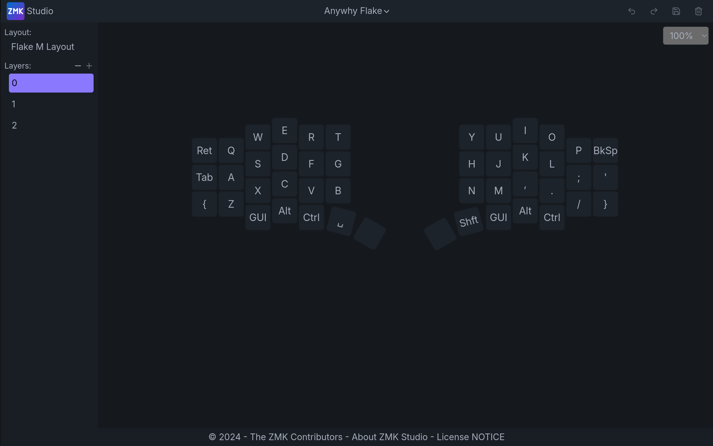
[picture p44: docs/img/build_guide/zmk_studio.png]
ZMK Studio interface


### Setting the Layout
1. In the left sidebar, select your keyboard size from the available options
2. This ensures all configurations match your specific Flake variant

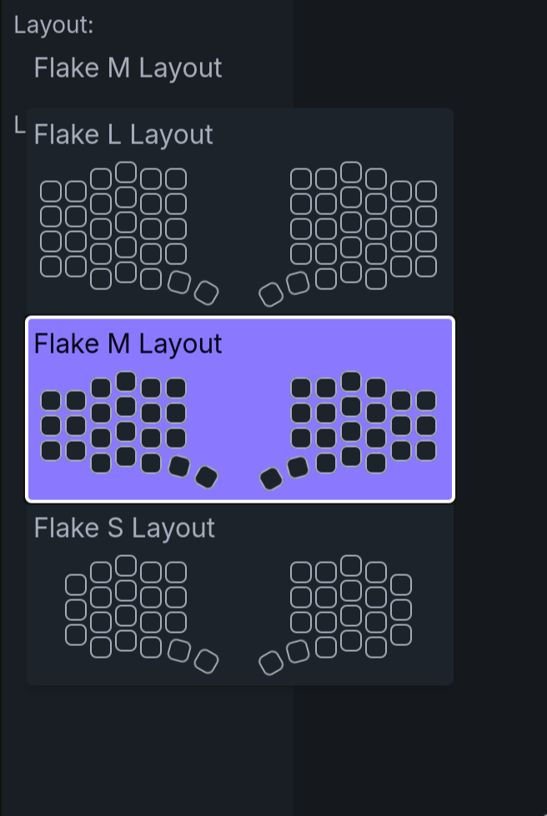
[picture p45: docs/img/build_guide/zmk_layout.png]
ZMK Studio layout selection


## Final Steps

Your Flake keyboard is now ready to use! You can:
- Continue using it via USB connection
- Disconnect the USB cable and switch to Bluetooth mode
- Customize your keyboard's layout and functions using ZMK Studio

Feel free to experiment with different configurations to find the setup that works best for you.

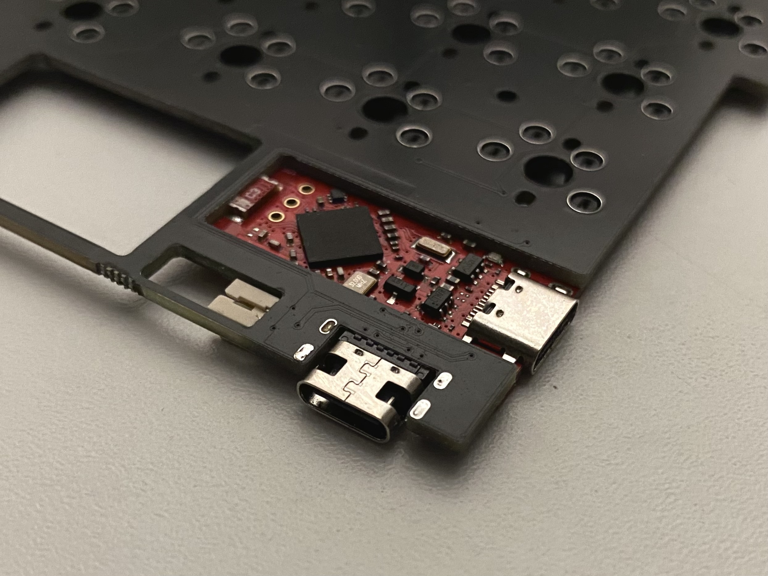
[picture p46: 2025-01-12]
docs/img/build_guide/controller_top.jpg

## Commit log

2025-01-11 pcb: remove unused footprints
2025-01-13 enclosure: plates: remove surface above controller
    [Enclosure-L-Bottom-Mirrored.step, Enclosure-L-Bottom.step, Enclosure-L-Plate-Mirrored.step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]
2025-01-13 enclosure: fix topology
    [Enclosure-L.FCStd, Enclosure-L.step, Enclosure-M.FCStd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]
2025-02-06 enclosure: split into individual files
    [Enclosure-L-Bottom-Left.step, Enclosure-L-Bottom-Right.step, Enclosure-L-Plate-Left.step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]
2025-06-08 Modified M,S
    [Flake.kicad_sch, left.kicad_sch, right.kicad_sch]
